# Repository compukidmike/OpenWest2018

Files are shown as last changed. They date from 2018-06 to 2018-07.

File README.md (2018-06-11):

# OpenWest2018 Electronic Badge

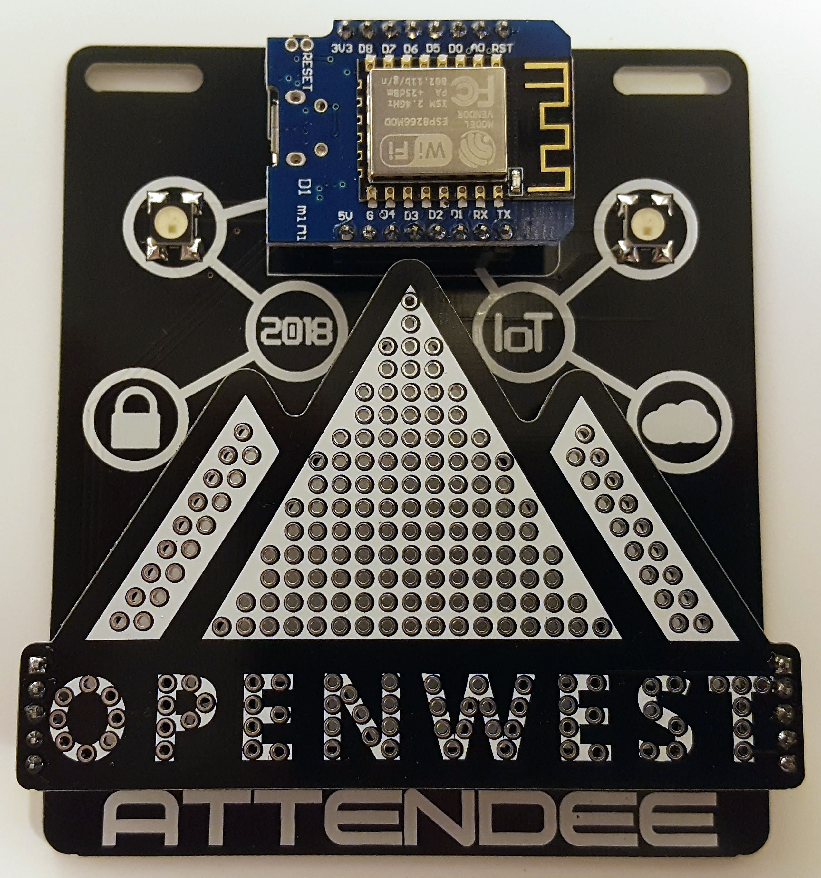
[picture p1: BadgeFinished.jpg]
BadgePic


## This year's badge is dedicated to our dear friend d3c4f. May his memory live on through many more awesome badges. 

The 2018 badge features WiFi connectivity, and all the badges are controlled by an MQTT server. The main controller is a WeMos D1 Mini, which uses the ESP8266 WiFi module.

**A note on battery life:** WiFi uses a lot of power. So do LEDs. The badges probably won't last more than a day on batteries. Take them out when you're not at the conference to avoid unnecessary battery drain. **Also, don't connect a USB cable while the batteries are in the badge. Bad things could happen.**

One of the fun things about this badge is that they're all controlled by this central server. There's no authentication on MQTT publications, so anyone can change what all the badges are doing. There are many programs to interact with MQTT servers. MQTTLens is a free chrome app that's very easy to use. If you want to learn more about MQTT go here https://www.hivemq.com/blog/mqtt-essentials-part-1-introducing-mqtt

We're using mosquitto (https://mosquitto.org/) for our local MQTT server. This server is only available at the conference. After the con is over, you'll have to connect the badge to your own server or an online service like adafruit.io. There are instructions below on how to do that.

The local MQTT server IP is 10.155.0.214, port 1883

The Feeds are setup as follows:
- Feed names: color1, color2, effect, effectspeed
- All feeds are prefixed by `feeds/`
- Colors are in Hex format (FFFFFF)
- Effectspeed is 0-255
- Effect is 0-6 (Off, On, Blink, Pulse, Alternate1, Alternate2, Rainbow)
- Must set retain flag on messages

The retain flag is important. It tells the server to keep the last message, and give it to any new client that subscribes to a feed. That means your badge won't have to wait until a new message is sent out to start displaying the proper colors, etc.

----------

## To get the Arduino IDE set up, you'll need to do the following:
(The Arduino IDE can be downloaded from https://www.arduino.cc/)
- Add the ESP8266 to the boards menu
  - From the Arduino IDE, click on File -> Preferences
  - Add this URL to the "Additional Boards Manager URLs" http://arduino.esp8266.com/stable/package_esp8266com_index.json
  - Click OK
  - Click on Tools > Board > Board Manager
  - Type ESP8266 in the search box
  - Find ESP8266 in the list and click Install
  
- Add the required libraries
  - Click Sketch > Include Library > Manage Libraries...
  - Search for and install the following libraries:
    - Adafruit IO Arduino
    - Adafruit MQTT Library
    - ArduinoHTTPClient
    - FastLED
    - WiFi
- Mac users need to download the WeMos driver at: https://wiki.wemos.cc/downloads (restart required after install).

## To connect the badge to your own WiFi network:
- Edit the following lines in the code:
  ```
  #define WLAN_SSID       "OPENWEST-GUEST"
  #define WLAN_PASS       "Openwest2018!"
  ```

## To connect the badge to a different MQTT server:
- Edit the following lines in the code:
  ```
  #define AIO_SERVER      "10.155.0.214"         // IP or URL for MQTT server
  #define AIO_SERVERPORT  1883                   // use 8883 for SSL
  #define AIO_USERNAME    "test"                 // Adafruit.io username
  #define AIO_KEY         "1234567890"           // Adafruit.io key
  ```
- To connect to adafruit.io, you'll need to create an account and then put your username and AIO key here. There are also more steps below for adafruit.io

## Adafruit.io Workaround
If you attended my talk about the badge, I talked about how adafruit.io is an MQTT server that doesn't fit the spec. One of the things I said was that they retain messages by default. Well, they changed that, but still don't support the retain flag, so there's a workaround. Please keep in mind that they made this change on April 22, 2018. I've been working with the badge code since long before that. They've updated their libraries to handle this, but I haven't had a chance to mess with it. If you get it working with the new Adafruit IO library, please submit a pull request.
Here's the blog post that talks about the change: https://io.adafruit.com/blog/notebook/2018/04/22/new-io-plus-and-mqtt-features/

### So, with that said, here's the workaround:
- All feed names are prefixed by your username, so they look like this: `<username>/feeds/<feed_name>`
- You'll need to set up a publish feed for each of your feed subscriptions with `/get` at the end (I know, it's ridiculous).
  - Example: ```Adafruit_MQTT_Publish color1get = Adafruit_MQTT_Publish(&mqtt, AIO_USERNAME "/feeds/color1/get");```
  - Note that the name must be different from the feed subscription (color1get vs color1)
- Then, near the bottom of the code after this line: ```Serial.println("MQTT Connected!");```
  - Add a publish for each feed:
    ```
    color1get.publish('\0');
    color2get.publish('\0');
    effectget.publish('\0');
    effectspeedget.publish('\0');
    delay(1000); //delay for receiving the packets
    ```
  - The delay is necessary to give time to get the response from the server and not drop packets
  
I know this is an ugly workaround. I'm sorry. On the bright side, it does show how to setup and publish data back to the server.

----------

If I missed anything, or you have something to add to this readme, please submit a pull request.

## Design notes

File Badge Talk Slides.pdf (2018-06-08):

# I've got an electronic conference badge, now what?

By @compukidmike

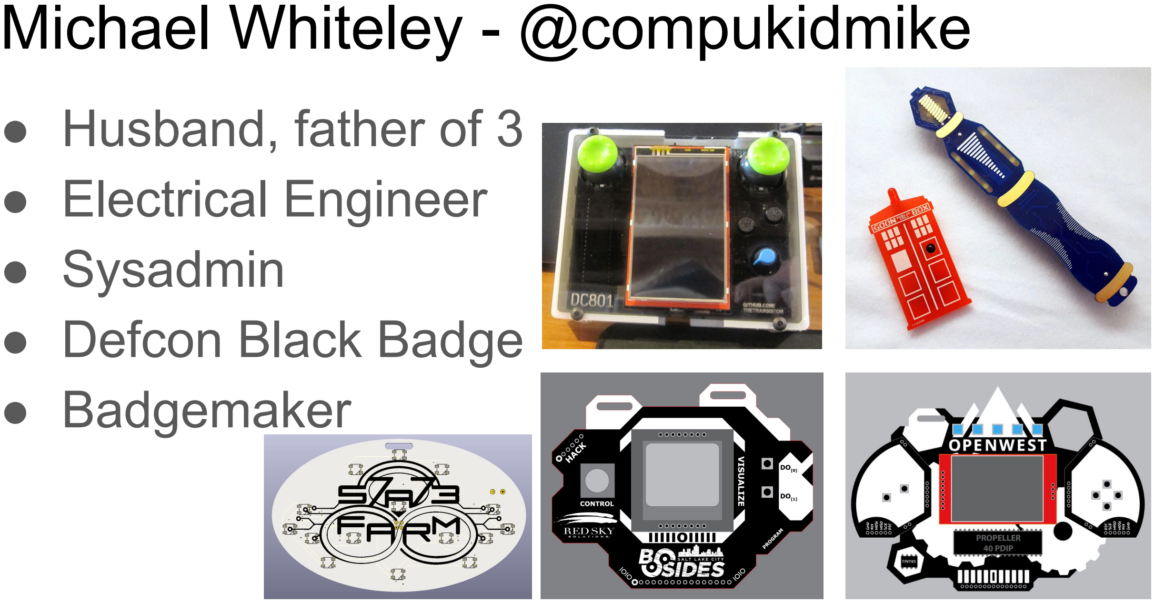
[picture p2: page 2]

### Michael Whiteley - @compukidmike

- Husband, father of 3
- Electrical Engineer
- Sysadmin
- Defcon Black Badge
- Badgemaker

## Badge Features

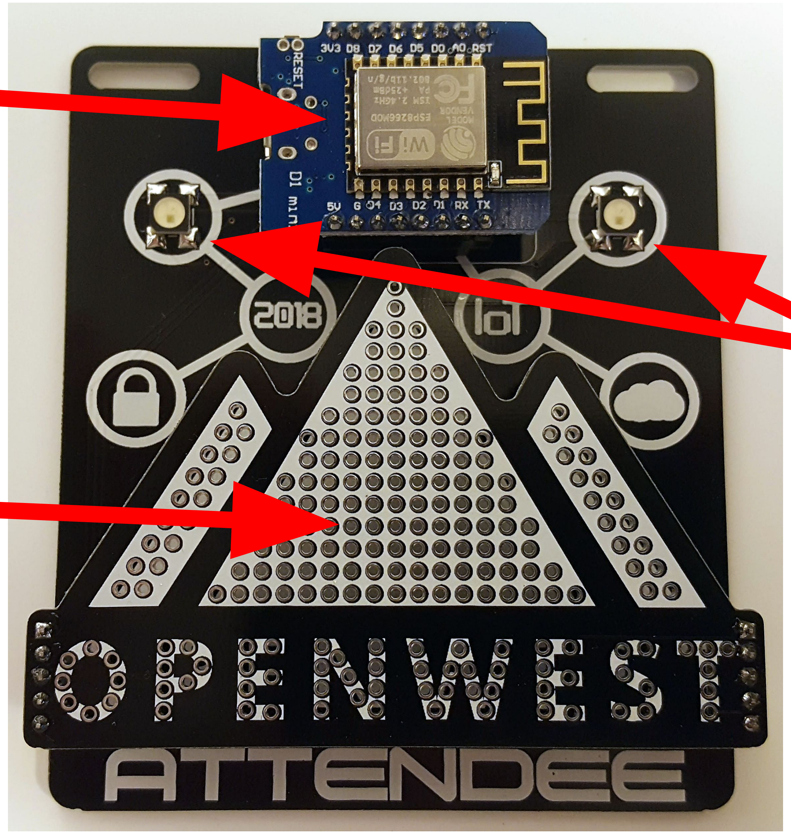
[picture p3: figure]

WiFi Module

RGB LEDs

Prototyping
Area

## WeMos D1 Mini - ESP8266

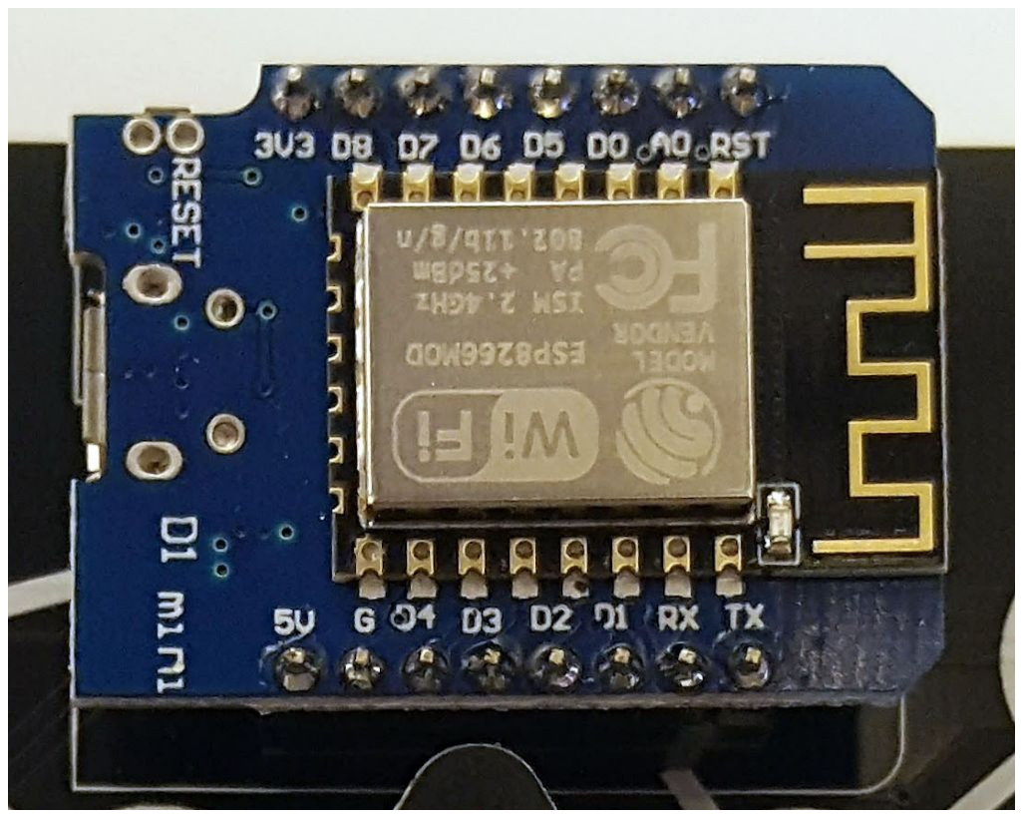
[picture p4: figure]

## Controlling the badge - MQTT

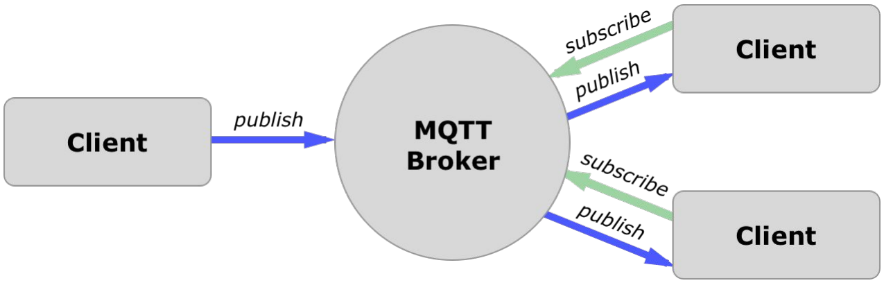
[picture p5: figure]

## MQTT Feeds

Feed names: color1, color2, effect, effectspeed

Colors are in Hex format (FFFFFF)

Effectspeed is 0-255

Effect is 0-6 (Off, On, Blink, Pulse, Alternate1, Alternate2, Rainbow)

Must set retain flag on messages

## Battery Power

WiFi is power hungry. So are LEDs.

Average 75mA to keep connected.

Sleep modes are your friend.

Deep sleep less than 1mA (requires jumper).

Or use USB power and don’t worry about it :)

## Arduino vs NodeMCU

NodeMCU has stability issues and requires rebuilding the core to add functionality. Scripts are written in Lua.

Arduino is stable and opens access to many community libraries.

Both require software to reprogram.

It really comes down to personal preference.

### Arduino - Change WiFi Settings

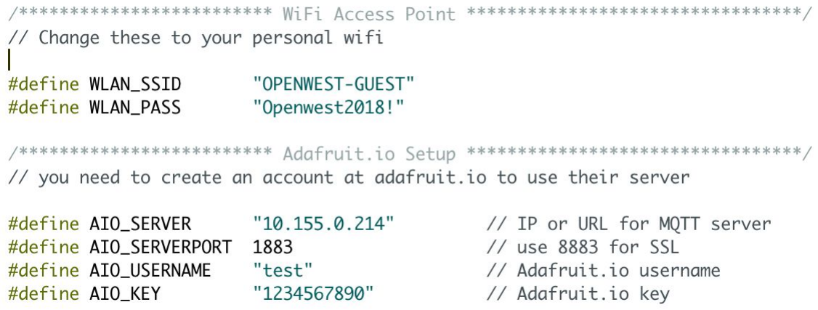
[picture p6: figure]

## Adafruit.io

### - Gives you a nice web interface for

talking to your IoT devices.

### - Free for small projects - (30 messages/minute, 5 feed limit) - Use triggers for doing things

### Arduino - Change MQTT Feeds

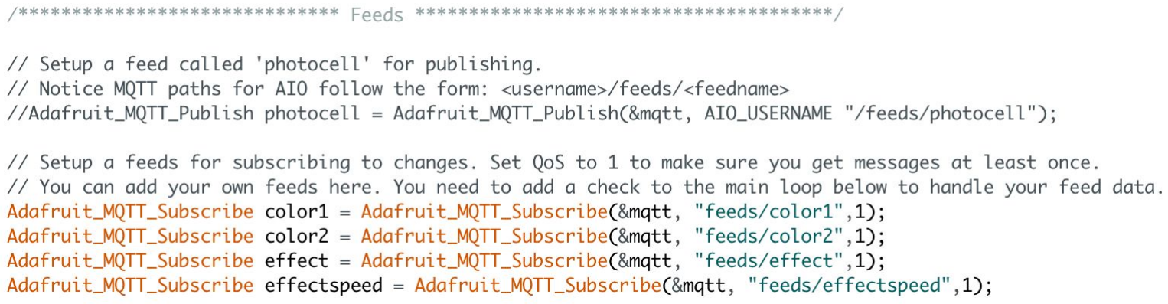
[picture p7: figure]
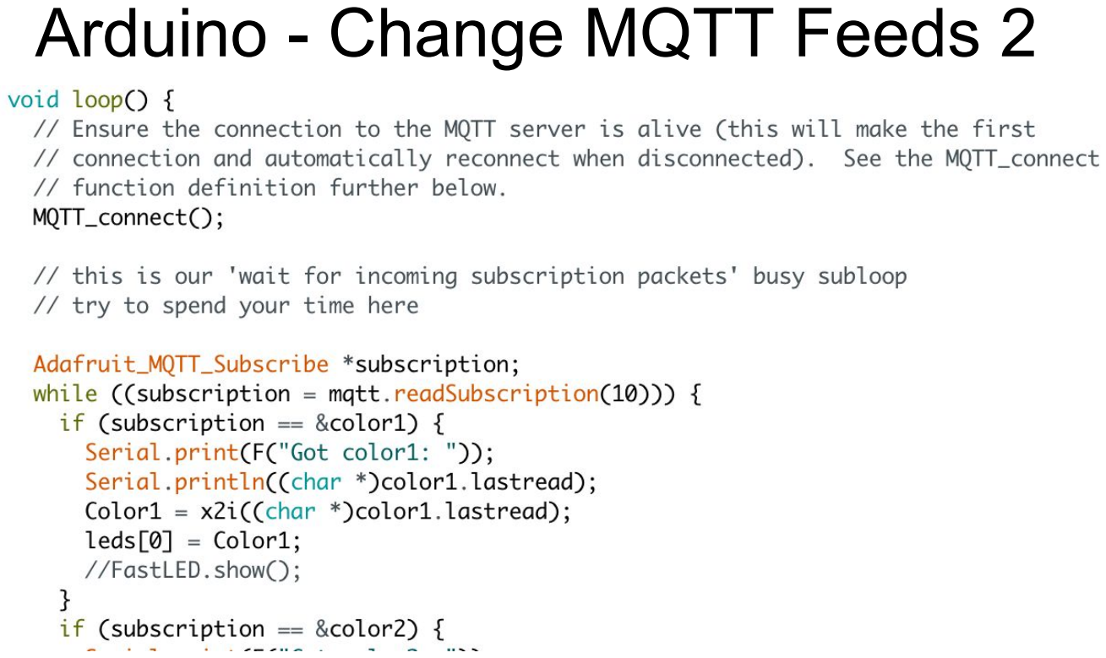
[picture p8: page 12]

### Arduino - Change MQTT Feeds 2

Protoboard - Make Your Own Add-On!

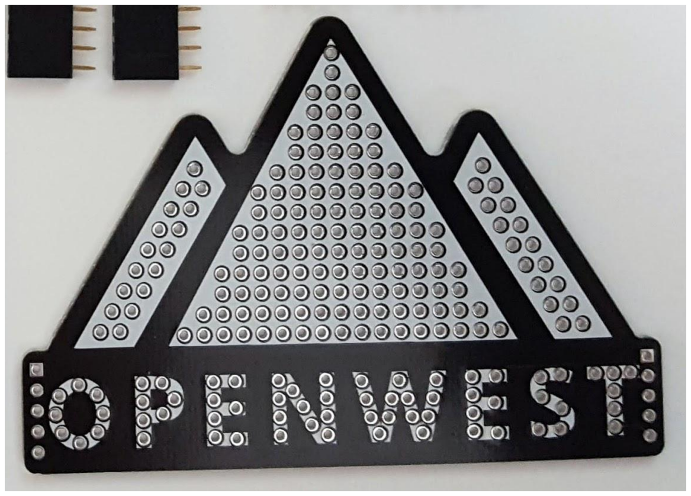
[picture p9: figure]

Protoboard - Make Your Own Add-On!

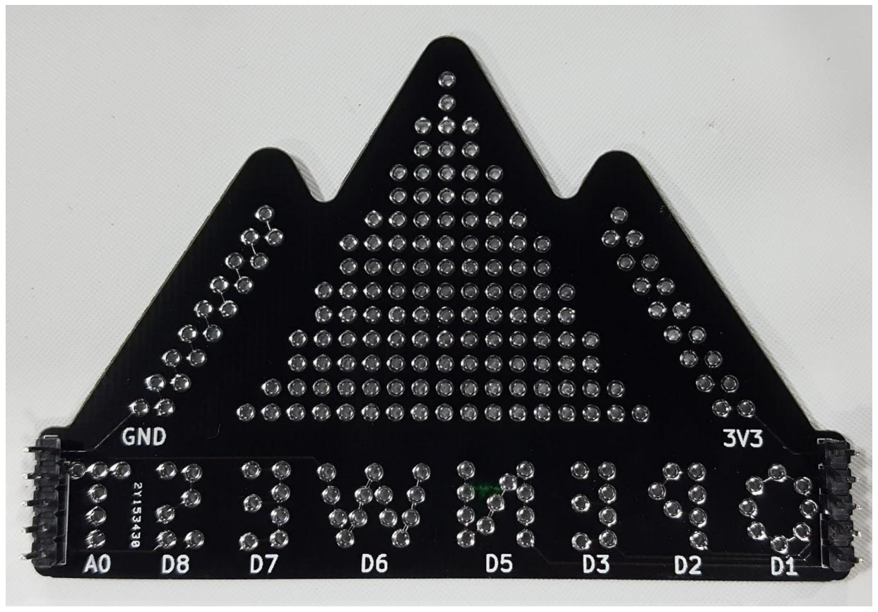
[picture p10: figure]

Protoboard - Make Your Own Add-On!

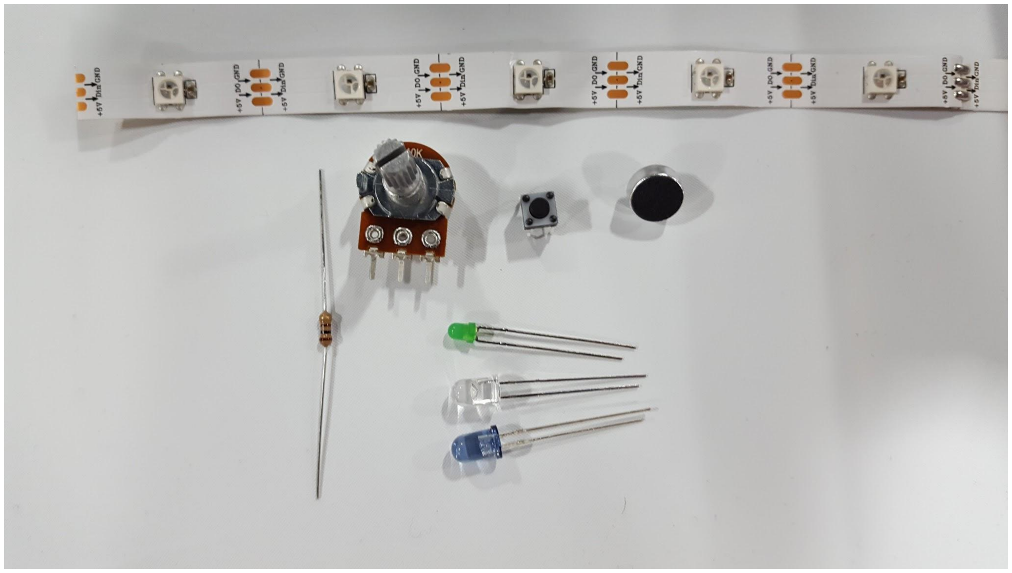
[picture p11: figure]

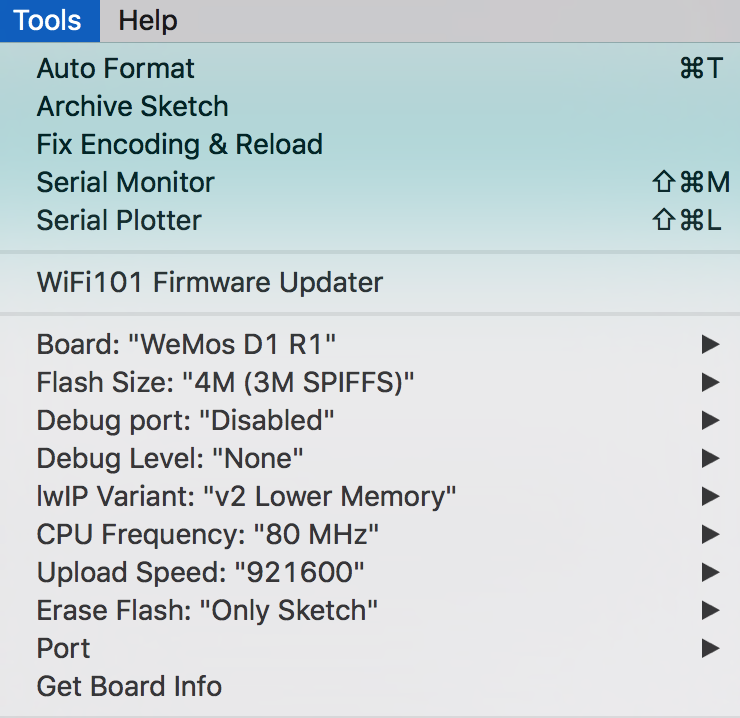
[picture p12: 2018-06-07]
Arduino Board Settings.png

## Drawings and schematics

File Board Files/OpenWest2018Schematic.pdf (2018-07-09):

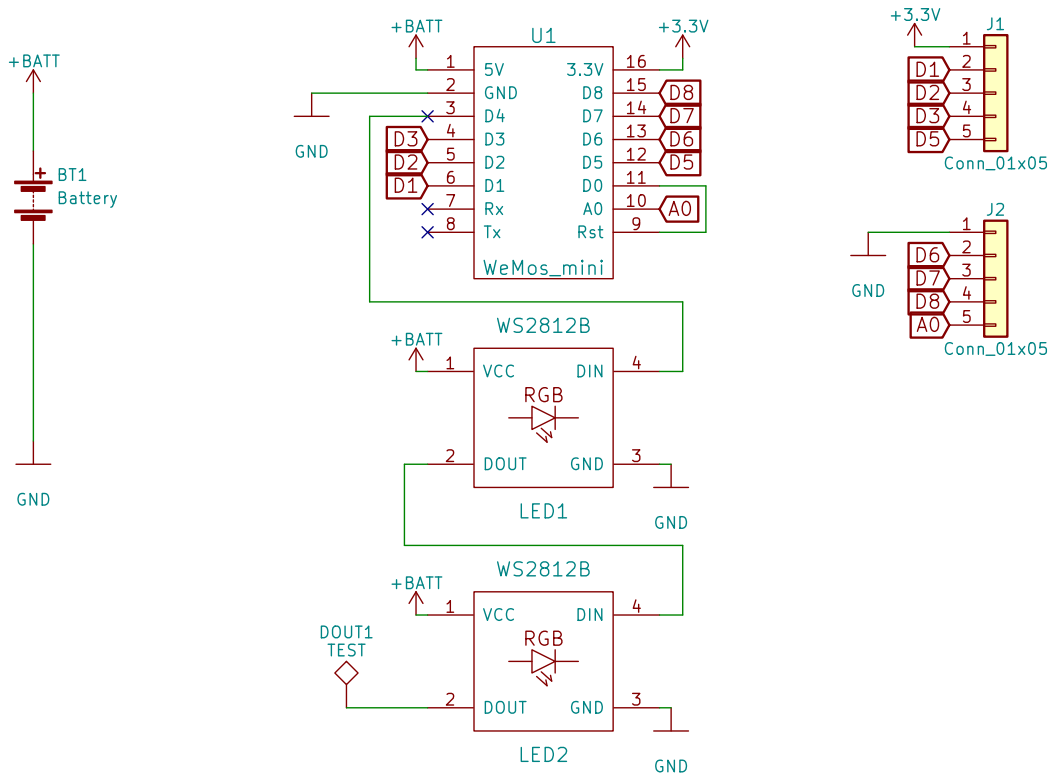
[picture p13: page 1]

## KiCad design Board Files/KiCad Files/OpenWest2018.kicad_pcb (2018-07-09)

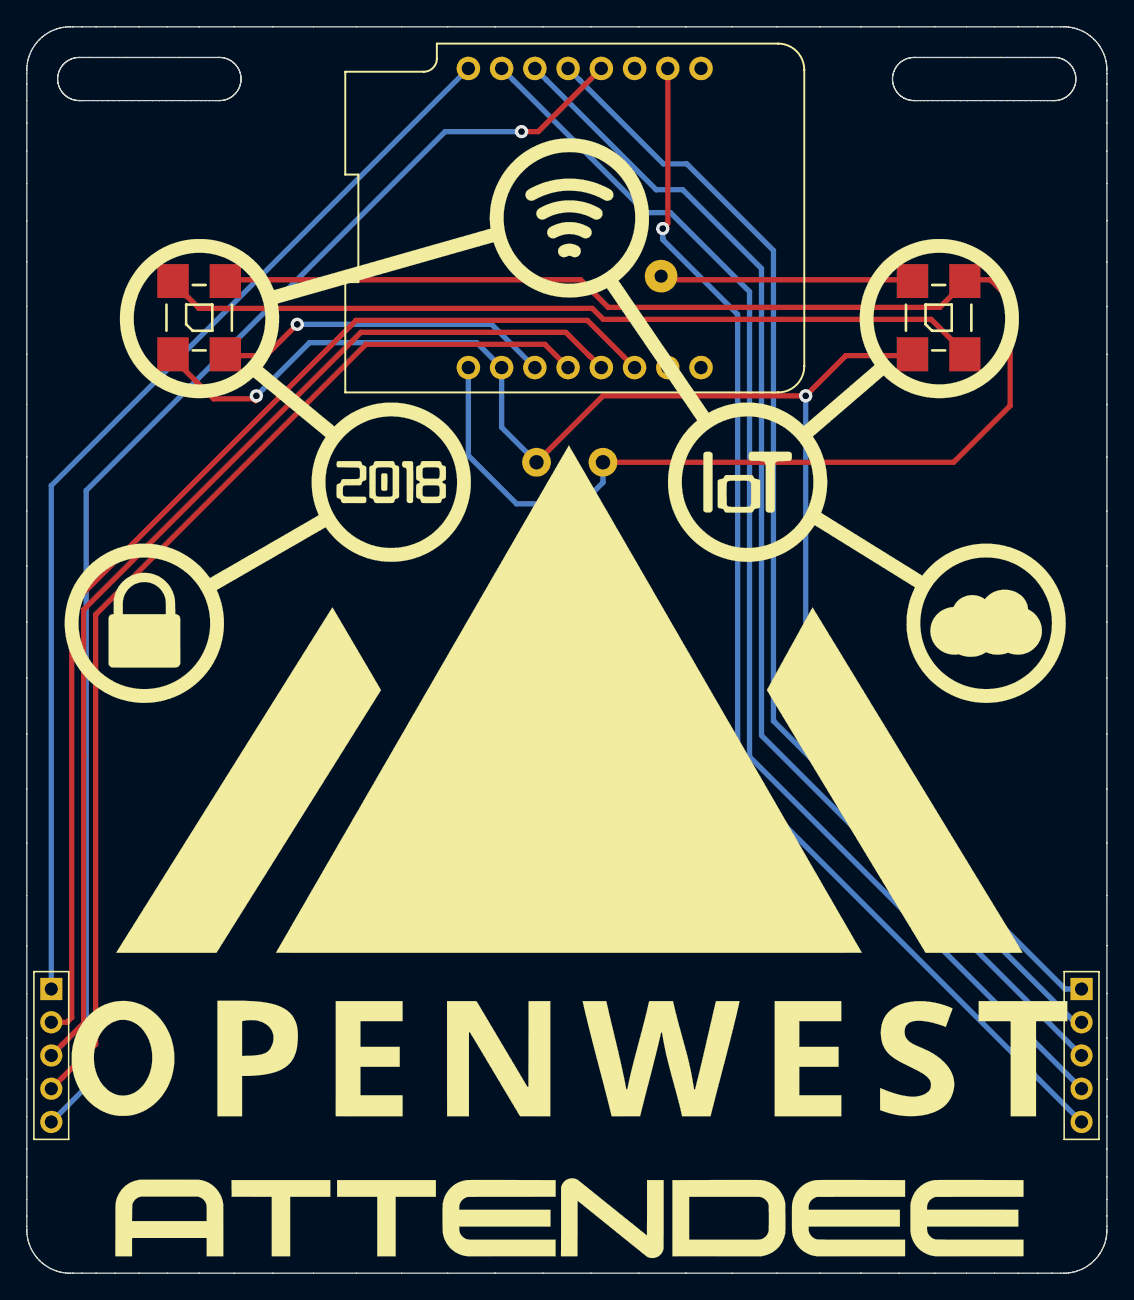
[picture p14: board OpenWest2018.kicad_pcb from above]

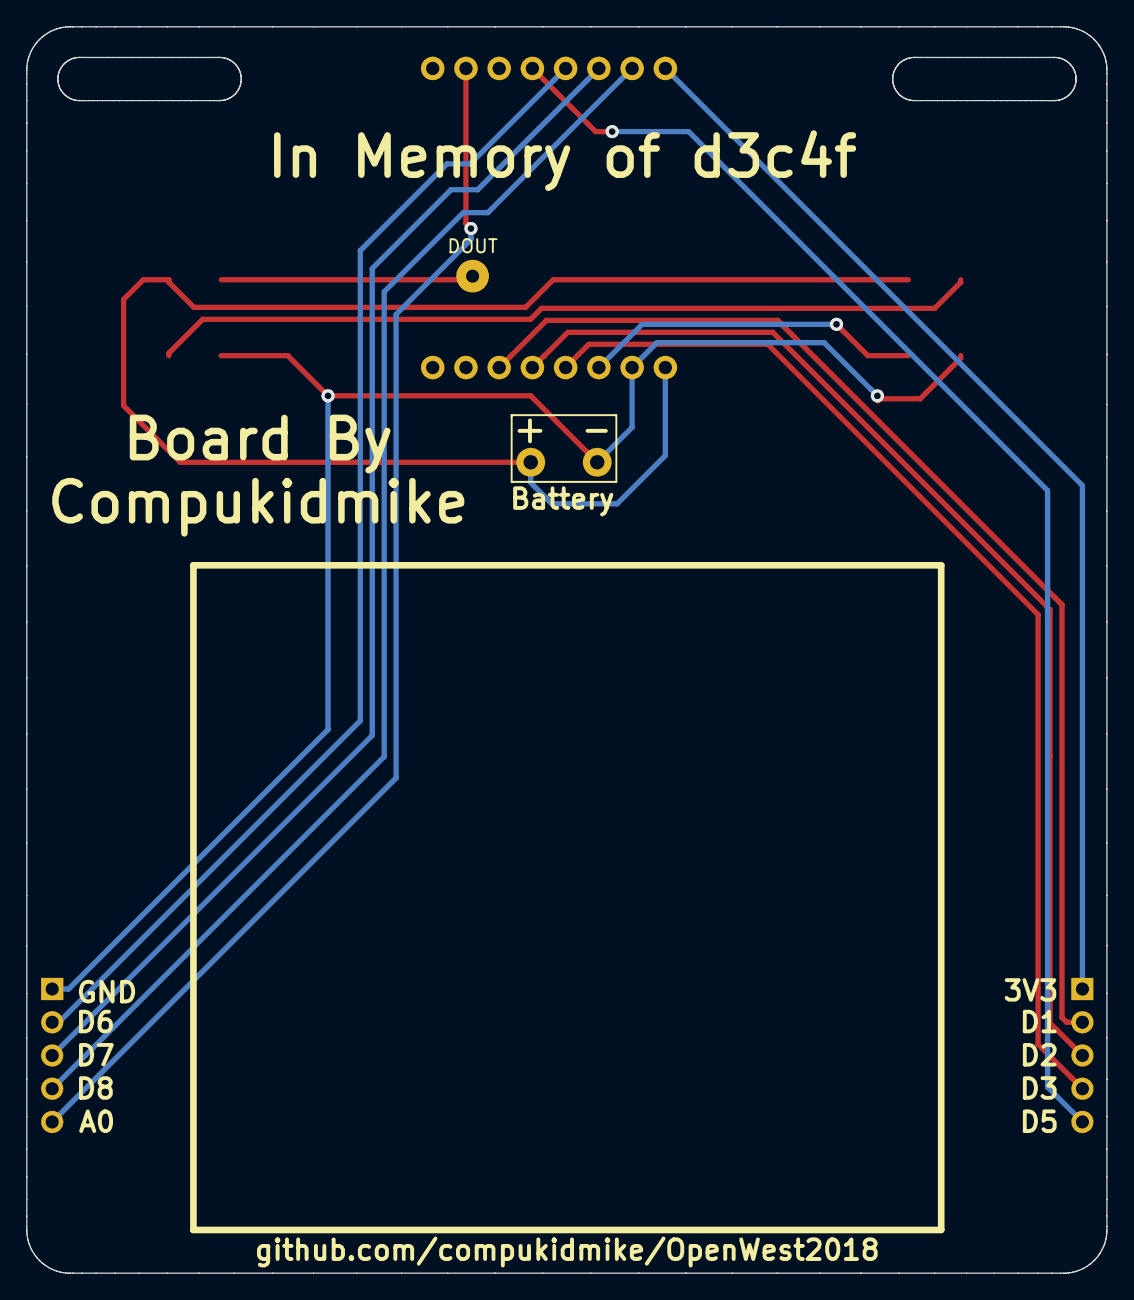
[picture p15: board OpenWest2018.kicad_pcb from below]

Board: 2 copper layers, 82.5 x 95.3 mm, 7 parts (2 on the bottom side), 15 nets.

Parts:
BT1: Battery; Battery-WireConn
DOUT: TEST; SolderWirePad_single_1mmDrill
J1, J2: Conn_01x05; Socket_Strip_Straight_1x05_Pitch2.54mm
LED1, LED2: WS2812B
U1: WeMos_mini; wemos-d1-mini-with-pin-header-and-connector

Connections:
+3V3: J1.1, U1.16
+BATT: BT1.1, LED1.1, LED2.1, U1.1
A0: J2.5, U1.10
D1: J1.2, U1.6
D2: J1.3, U1.5
D3: J1.4, U1.4
D5: J1.5, U1.12
D6: J2.2, U1.13
D7: J2.3, U1.14
D8: J2.4, U1.15
GND: BT1.2, J2.1, LED1.3, LED2.3, U1.2
unnamed: DOUT.1, LED2.2
unnamed: LED1.2, LED2.4
unnamed: LED1.4, U1.3
unnamed: U1.9, U1.11

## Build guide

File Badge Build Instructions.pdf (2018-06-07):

# Badge Build Instructions

# OpenWest 2018

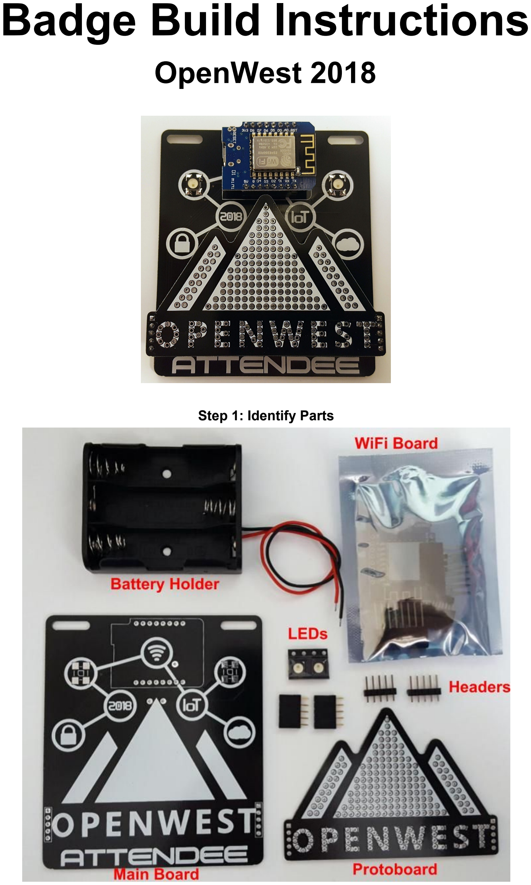
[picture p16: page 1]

Step 1: Identify Parts

Step 2: Place LEDs

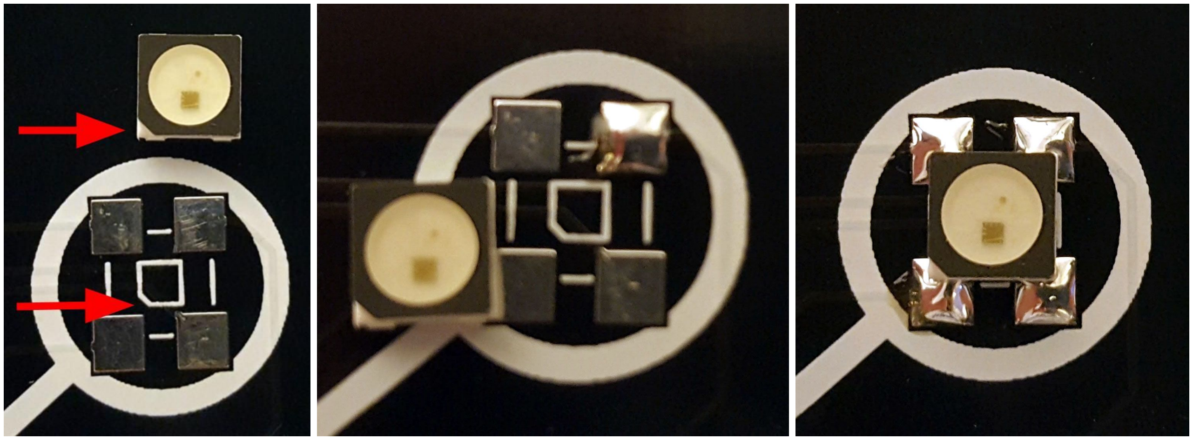
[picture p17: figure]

Please note LED orientation. Align the marked corners on the LED and the board. Place solder on one pad first. Using tweezers, hold the LED and place it on the board while simultaneously re-melting the solder with the iron. Remove the iron and the solder will solidify, holding the LED in place. Now solder the other 3 corners of the LED.

Step 3: Protoboard

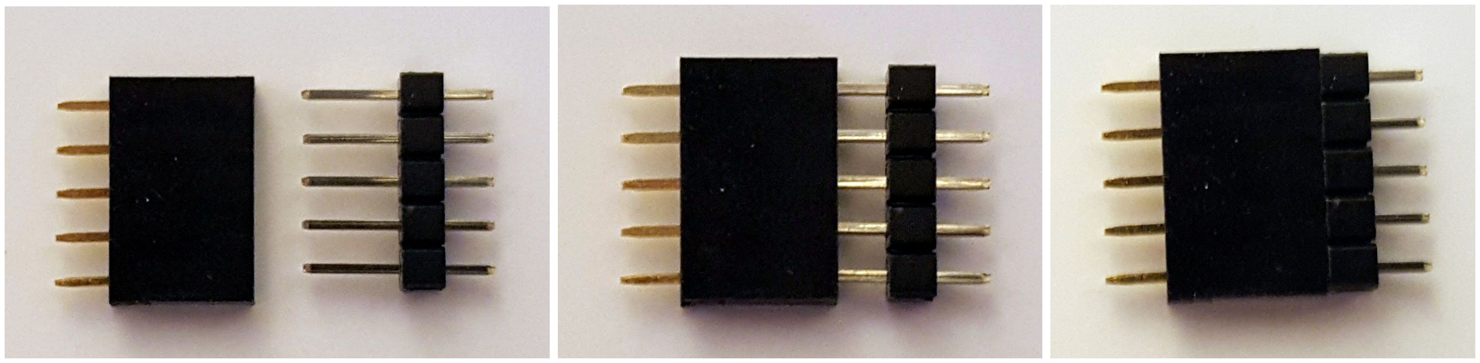
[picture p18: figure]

Put the short headers together as shown. Make 2 sets.

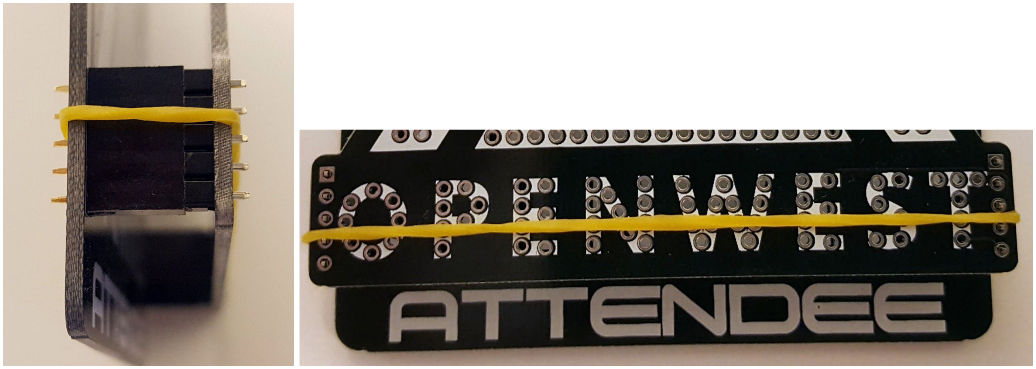
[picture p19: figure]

Place the headers into the main board, gold pins first. Then put the protoboard on top. Use a rubber band to hold the protoboard in place while you solder it. Solder one pin on each side of each header. Remove the rubber band and finish soldering the rest of the pins.

Step 4: WiFi Board

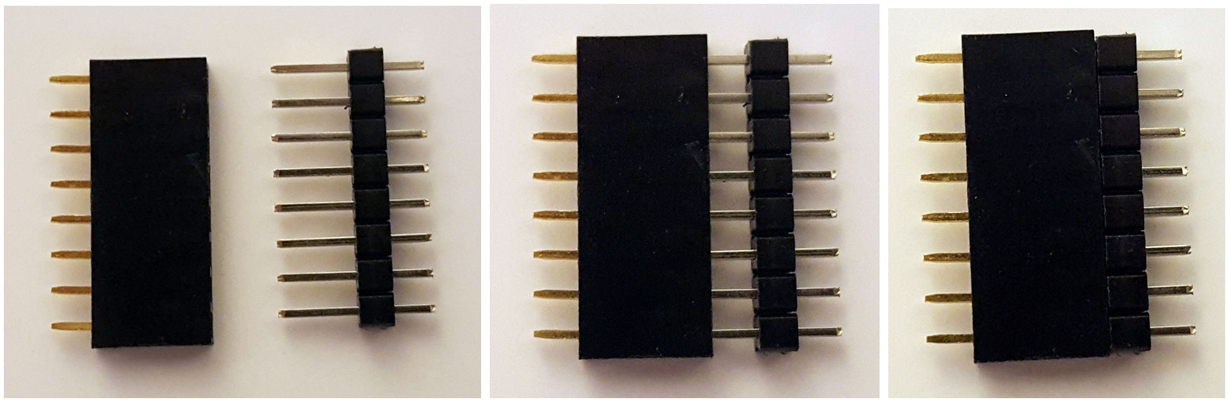
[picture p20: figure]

Put the longer headers together like before. Make 2 sets.

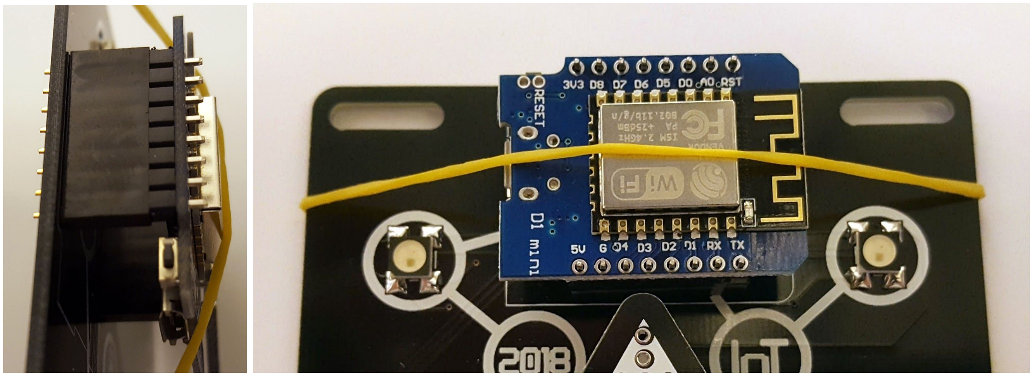
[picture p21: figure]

Place the headers into the main board, gold pins first. Then put the WiFi board on top. Use a rubber band to hold the WiFi board in place while you solder it. Solder one pin on each side of each header. Remove the rubber band and finish soldering the rest of the pins.

Step 5: Battery Holder

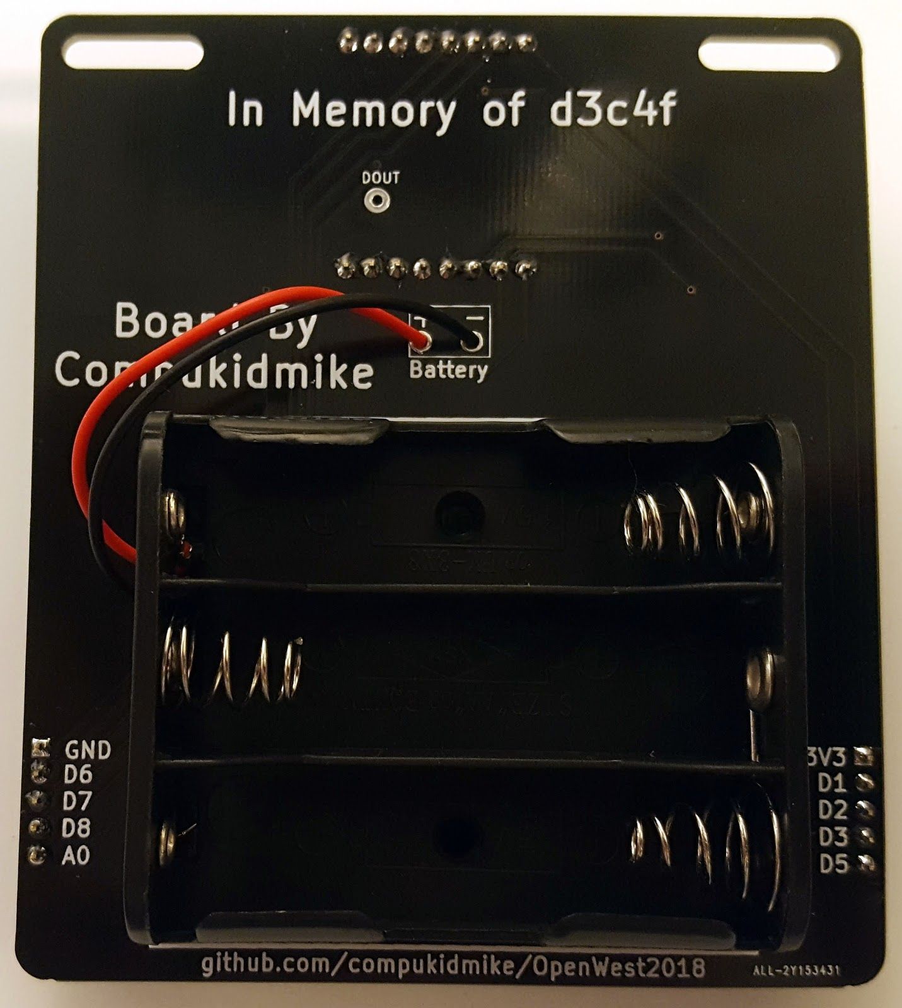
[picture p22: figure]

Place the battery holder on the back using the sticky pad. Cut the wires to length and strip the ends. Place the stripped ends into the holes marked battery (Red to +, Black to -). Flip the board over and solder the wires.

Congratulations! Your badge is finished! For more info about how it works and what you can do with it, visit github.com/compukidmike/OpenWest2018

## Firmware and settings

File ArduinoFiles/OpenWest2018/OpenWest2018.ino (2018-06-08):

/***************************************************
 * OpenWest2018 Badge Code
 * by compukidmike
 * 
 * This code relies on the following libraries:
 * - Adafruit MQTT
 * - FastLED
 * - Arduino Wifi
 * 
 * This code borrows code snippets from Adafruit and http://forum.arduino.cc/index.php?topic=145385.0
 * There are probably others that I forgot. I don't claim any of this code as my own.
 ***************************************************/


#include <ESP8266WiFi.h>
#include "Adafruit_MQTT.h"
#include "Adafruit_MQTT_Client.h"

#define FASTLED_ESP8266_RAW_PIN_ORDER
#include "FastLED.h"

#define PIXEL_PIN     2
#define PIXEL_COUNT   2
#define PIXEL_TYPE    NEO_GRB + NEO_KHZ800

/************************* WiFi Access Point *********************************/
// Change these to your personal wifi

#define WLAN_SSID       "OPENWEST-GUEST"
#define WLAN_PASS       "Openwest2018!"

/************************* Adafruit.io Setup *********************************/
// you need to create an account at adafruit.io to use their server

#define AIO_SERVER      "10.155.0.214"         // IP or URL for MQTT server
#define AIO_SERVERPORT  1883                   // use 8883 for SSL
#define AIO_USERNAME    "test"                 // Adafruit.io username
#define AIO_KEY         "1234567890"           // Adafruit.io key

/************ Global State (you don't need to change this!) ******************/

// Create an ESP8266 WiFiClient class to connect to the MQTT server.
WiFiClient client;
// or... use WiFiFlientSecure for SSL
//WiFiClientSecure client;

// Setup the MQTT client class by passing in the WiFi client and MQTT server and login details.
Adafruit_MQTT_Client mqtt(&client, AIO_SERVER, AIO_SERVERPORT, AIO_USERNAME, AIO_KEY);

/****************************** Feeds ***************************************/

// Setup a feed called 'photocell' for publishing.
// Notice MQTT paths for AIO follow the form: <username>/feeds/<feedname>
//Adafruit_MQTT_Publish photocell = Adafruit_MQTT_Publish(&mqtt, AIO_USERNAME "/feeds/photocell");

// Setup a feeds for subscribing to changes. Set QoS to 1 to make sure you get messages at least once.
// You can add your own feeds here. You need to add a check to the main loop below to handle your feed data.
Adafruit_MQTT_Subscribe color1 = Adafruit_MQTT_Subscribe(&mqtt, "feeds/color1",1);
Adafruit_MQTT_Subscribe color2 = Adafruit_MQTT_Subscribe(&mqtt, "feeds/color2",1);
Adafruit_MQTT_Subscribe effect = Adafruit_MQTT_Subscribe(&mqtt, "feeds/effect",1);
Adafruit_MQTT_Subscribe effectspeed = Adafruit_MQTT_Subscribe(&mqtt, "feeds/effectspeed",1);

/*************************** Sketch Code ************************************/

CRGB leds[PIXEL_COUNT]; //variable for storing led color data

byte Effect = 0; //Current Effect
byte Speed = 0; //Effect Speed
int counter1 = 0;
int counter2 = 0;
long Color1 = 0;
long Color2 = 0;
long nextPing = 0; //time until next keepalive ping

// Bug workaround for Arduino 1.6.6, it seems to need a function declaration
// for some reason (only affects ESP8266, likely an arduino-builder bug).
void MQTT_connect();

template <typename T>
void updateLEDs(CRGB (&led)[PIXEL_COUNT], T first_color, T second_color) {

  for (int i= 0; i<PIXEL_COUNT; i ++) {
    if (i % 2 != 0 )
      led[i] = first_color;
    else
      led[i] = second_color;
  }

}
void setup() {
  FastLED.addLeds<NEOPIXEL, PIXEL_PIN>(leds, PIXEL_COUNT);
  leds[0] = 0;
  leds[1] = 0;
  FastLED.show();
  
  Serial.begin(115200);
  
  byte mac[6];
  WiFi.macAddress(mac);
  Serial.print("MAC: "); //Print MAC address
  Serial.print(mac[0],HEX);
  Serial.print(":");
  Serial.print(mac[1],HEX);
  Serial.print(":");
  Serial.print(mac[2],HEX);
  Serial.print(":");
  Serial.print(mac[3],HEX);
  Serial.print(":");
  Serial.print(mac[4],HEX);
  Serial.print(":");
  Serial.println(mac[5],HEX);
  
  delay(1); //10

  Serial.println(F("OpenWest 2018 Badge"));

  // Connect to WiFi access point.
  Serial.println(); Serial.println();
  Serial.print("Connecting to ");
  Serial.println(WLAN_SSID);
  
  WiFi.mode(WIFI_STA);
  WiFi.begin(WLAN_SSID, WLAN_PASS);
  while (WiFi.status() != WL_CONNECTED) {
    delay(500);
    Serial.print(".");
  }
  Serial.println();

  Serial.println("WiFi connected");
  Serial.println("IP address: "); Serial.println(WiFi.localIP());

  // Setup MQTT subscription for onoff feed.
  mqtt.subscribe(&color1);
  mqtt.subscribe(&color2);
  mqtt.subscribe(&effect);
  mqtt.subscribe(&effectspeed);
  //}
}

uint32_t x=0;

void loop() {
  // Ensure the connection to the MQTT server is alive (this will make the first
  // connection and automatically reconnect when disconnected).  See the MQTT_connect
  // function definition further below.
  MQTT_connect();

  // this is our 'wait for incoming subscription packets' busy subloop
  // try to spend your time here

  Adafruit_MQTT_Subscribe *subscription;
  while ((subscription = mqtt.readSubscription(10))) {
    if (subscription == &color1) {
      Serial.print(F("Got color1: "));
      Serial.println((char *)color1.lastread);
      Color1 = x2i((char *)color1.lastread);
      leds[0] = Color1;
      //FastLED.show();
    }
    if (subscription == &color2) {
      Serial.print(F("Got color2: "));
      Serial.println((char *)color2.lastread);
      Color2 = x2i((char *)color2.lastread);
      leds[1] = Color2;
      //FastLED.show();
    }
    if (subscription == &effect) {
      Serial.print(F("Got effect: "));
      Serial.println((char *)effect.lastread);
      Effect = atoi((char *)effect.lastread);
      counter1 = 0;
      counter2 = 0;
    }
    if (subscription == &effectspeed) {
      Serial.print(F("Got speed: "));
      Serial.println((char *)effectspeed.lastread);
      Speed = atoi((char *)effectspeed.lastread);
    }
  }

  //Update LEDs based on Effect and Speed - Runs every ~10ms
  //Effect 0 = Off
  //Effect 1 = On
  //Effect 2 = Blink
  //Effect 3 = Pulse
  //Effect 4 = Alternate 1
  //Effect 5 = Alternate 2
  //Effect 6 = Rainbow

  switch (Effect){
      case 0: //off
        updateLEDs(leds, 0, 0);
        break;
      case 1: //on
        updateLEDs(leds, Color1, Color2);
        break;
      case 2: //blink
        counter1 += Speed;
        if(counter1 > 255){
          counter1 = 0;
          if(counter2 == 0){
            updateLEDs(leds, 0 ,0);
            counter2 = 1;
          }else{
            updateLEDs(leds, Color1, Color2);
            counter2 = 0;
          }
        }
        break;
      case 3: //Pulse
        if(counter2 == 0){ //count up
          counter1 += Speed;
          if(counter1 > 255){
            counter2 = 1;
            counter1 = 255;
          }
        }else{
          counter1 -= Speed;
          if(counter1 < 0){ //count down
            counter2 = 0;
            counter1 = 0;
          }
        }
        updateLEDs(leds, (Color1 % counter1), (Color2 % counter1));
        //leds[0] = Color1;
        //leds[0] %= counter1;
        //leds[1] = Color2;
        //leds[1] %= counter1;
        break;
      case 4: //Alternate Colors 1
        counter1 += Speed;
        if(counter1 > 255){
          counter1 = 0;
          if(counter2 == 0){
            counter2 = 1;
            updateLEDs(leds, Color1, Color2);
          }else{
            counter2 = 0;
            updateLEDs(leds, Color2, Color1);
          }
        }
        break;
      case 5: //Alternate Colors 2
        counter1 += Speed;
        if(counter1 > 255){
          counter1 = 0;
          if(counter2 == 0){
            counter2 = 1;
            updateLEDs(leds, Color1, Color1);
          }else{
            counter2 = 0;
            updateLEDs(leds, Color2, Color2);
          }
        }
        break;
      case 6: //Rainbow
        counter1 += Speed;
        if(counter1>255) counter1 = 0;
        updateLEDs(leds, CHSV(counter1,187,128), CHSV(counter1,187,128));
        break;
      default:
        updateLEDs(leds, Color1, Color2);
    }
  
  FastLED.show();

/*
  // This is sample code for publishing to the MQTT server
  Serial.print(F("\nSending photocell val "));
  Serial.print(x);
  Serial.print("...");
  if (! photocell.publish(x++)) {
    Serial.println(F("Failed"));
  } else {
    Serial.println(F("OK!"));
  }
*/
  // ping the server to keep the mqtt connection alive
  // NOT required if you are publishing once every KEEPALIVE seconds
  if(millis() > nextPing){
    nextPing = millis() + 60000; //1 minute
    if(! mqtt.ping()) {
      mqtt.disconnect();
    }
  }
  
  delay(2);
}

// Function to connect and reconnect as necessary to the MQTT server.
// Should be called in the loop function and it will take care if connecting.
void MQTT_connect() {
  int8_t ret;

  // Stop if already connected.
  if (mqtt.connected()) {
    return;
  }

  Serial.print("Connecting to MQTT... ");

  uint8_t retries = 3;
  while ((ret = mqtt.connect()) != 0) { // connect will return 0 for connected
       Serial.println(mqtt.connectErrorString(ret));
       Serial.println("Retrying MQTT connection in 5 seconds...");
       mqtt.disconnect();
       delay(5000);  // wait 5 seconds
       retries--;
       if (retries == 0) {
         // basically die and wait for WDT to reset me
         while (1);
       }
  }
  Serial.println("MQTT Connected!");
}

int x2i(char *s) //convert hex string to integer
{
 int x = 0;
 for(;;) {
   char c = *s;
   if (c >= '0' && c <= '9') {
      x *= 16;
      x += c - '0'; 
   }
   else if (c >= 'A' && c <= 'F') {
      x *= 16;
      x += (c - 'A') + 10; 
   }
   else if (c >= 'a' && c <= 'f') {
      x *= 16;
      x += (c - 'a') + 10;
}
   else break;
   s++;
 }
 return x;
}

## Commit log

2018-06-07 add arduino file folder
2018-06-08 Added Mac WeMos driver download link.
2018-06-08 add for loop for multiple leds
2018-07-09 Add board files
    [OpenWest2018.kicad_pcb, OpenWest2018.sch]
2018-07-09 added schematic pdf
